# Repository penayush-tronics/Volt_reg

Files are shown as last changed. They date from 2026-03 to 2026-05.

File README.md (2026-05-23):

# Simple Voltage Regulator Board
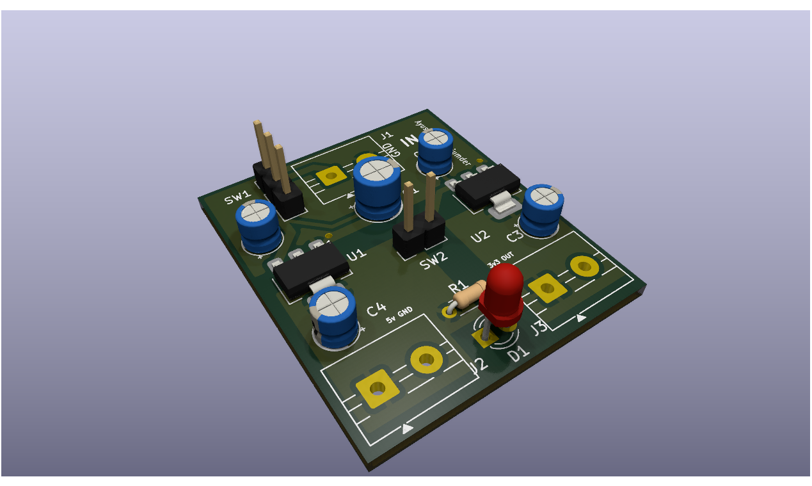
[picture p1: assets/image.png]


This is a simple voltage regulator board, which takes in between 6.5V and upto 20V input, and outputs both 5V and 3.3V, with a maximum current output of 1A. This project uses the well-known AMS1117 step-down linear voltage regulators, which are Low Dropout Regulators, meaning the voltage drop across them is less than normal linear regulators. Here there are 2 of them, 1 of which steps down (decreases) 6.5V-20V to 5V, and the other one which steps down 5V from the previous LDO, into 3.3V. 

# How to use the board: 

Here is a 3D model of the board: 

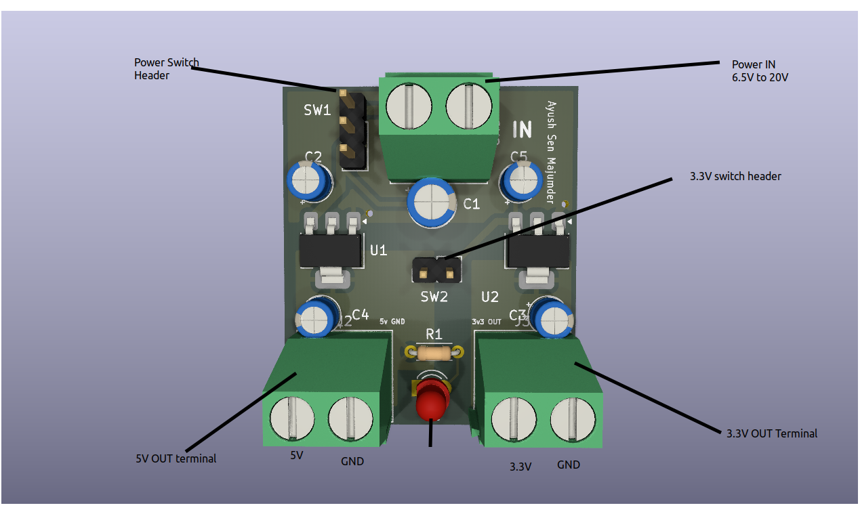
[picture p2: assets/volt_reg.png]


You will see 3 screw terminal blocks; 1 on the top side, and 2 on the bottom. The one on top, labelled IN is the input block. Here, you should screw in the input wires, which can be from a battery or any power source up to 20V. Be mindful of the polarity! You can see GND is labelled next to the ground input. 

Next, to turn the board on, add a short jumper to the 3 header pins next to the input. Short/connect the top 2 pins to connect the board to power. To disconnect, move the jumper to the bottom 2 pins. After turning it on, you will see the red LED glow. This means the 5V output and the board is turned on. You can now connect the 5V output (on the bottom left side) to anything you want to power, but once again be mindful of polarity. It is labelled on the board. 

To turn on the 3.3V output, use a short header to connect the 2 header pins in the center of the board. Now the 3.3V output is turned on (bottom right side of board) and you can connect it to anything that runs on 3.3V, such as microcontrollers and development boards. 

# Why I made this board

I found myself struggling to power my electronic components, such as motors with an arduino. You cannot run them directly with the 5V output of the arduino due to current constraints, as well as you risk frying the arduino. In such cases I struggled to power them seperately with a quality, high current power source. Normal batteries and Li-Ion rechargable batteries do not have the required voltage either, and running from USB power is not ideal. Hence I developed this regulator board, so a stable and proper 5V and 3.3V power source can be used for projects.

# Schematics 

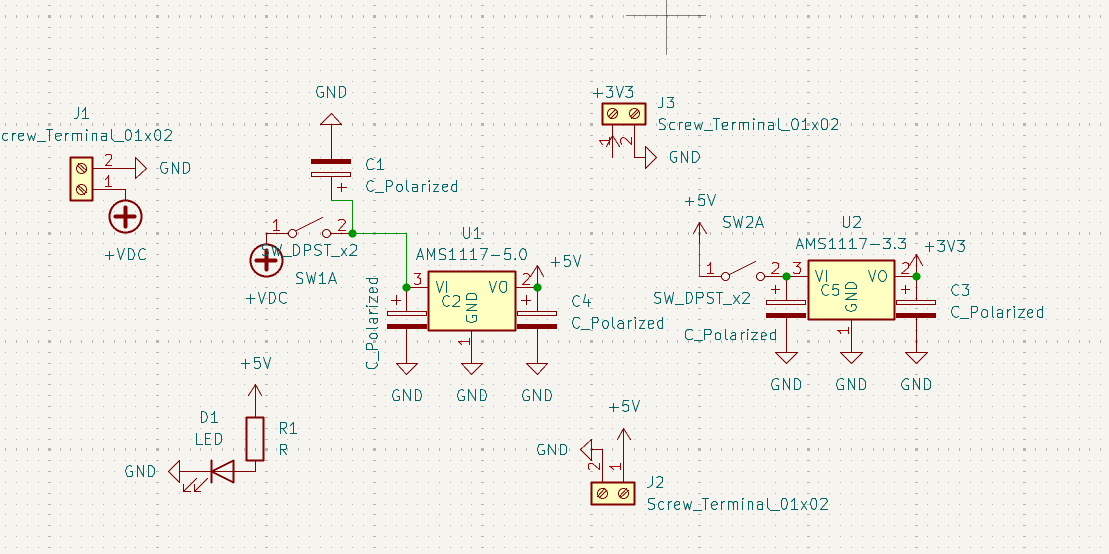
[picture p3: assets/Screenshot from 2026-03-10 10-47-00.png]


# PCB design 

KiCAD editor:
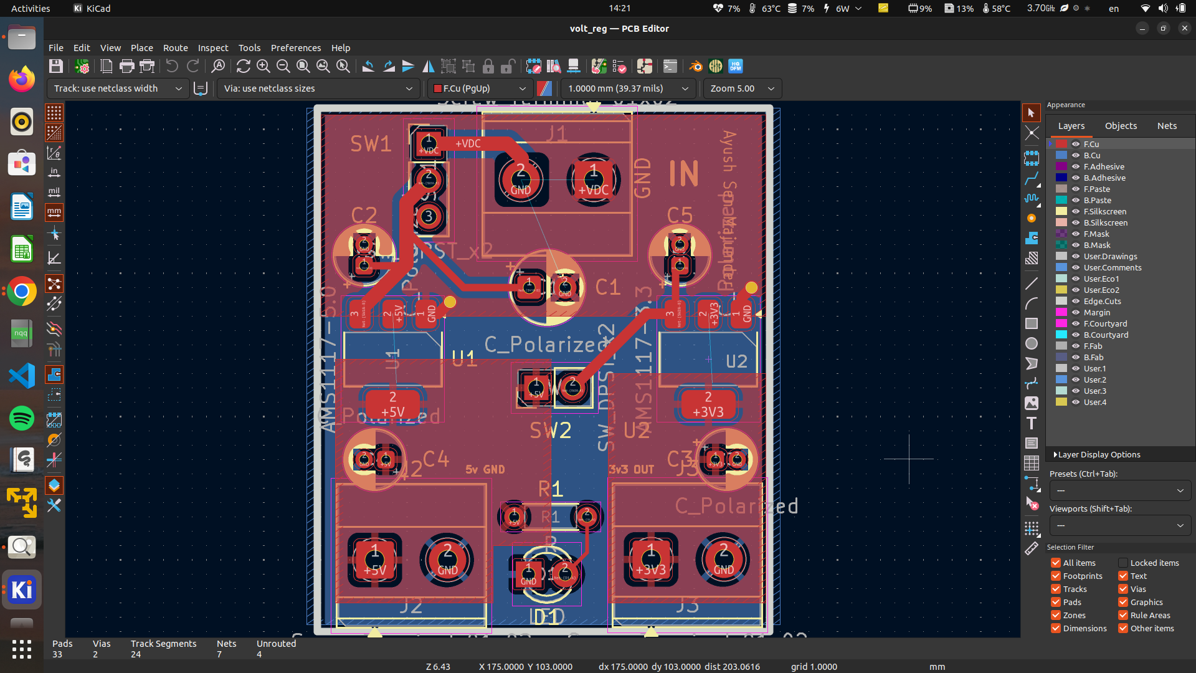
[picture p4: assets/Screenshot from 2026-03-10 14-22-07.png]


3D model-

Front side: 

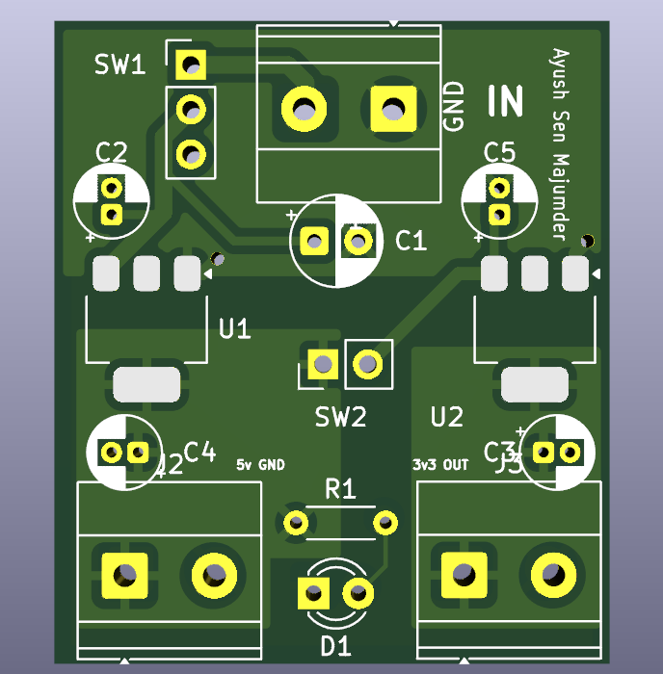
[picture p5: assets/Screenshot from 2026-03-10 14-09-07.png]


Back side:

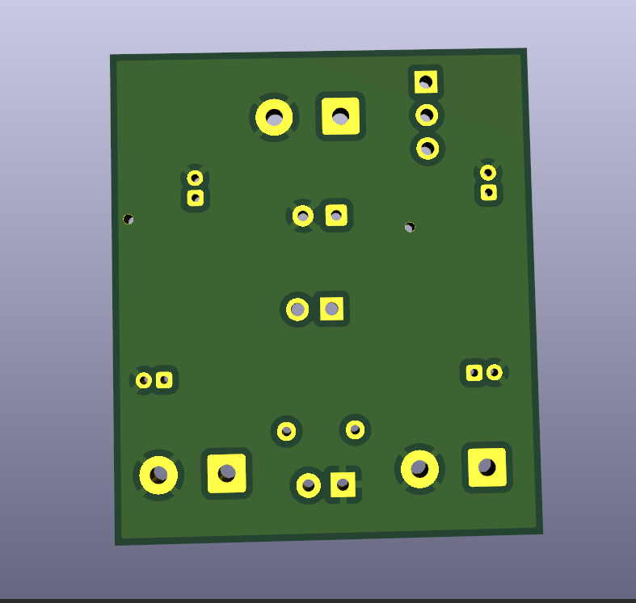
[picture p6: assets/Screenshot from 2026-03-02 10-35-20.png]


All Schematics and PCB file (including gerber zip) is available in the PCB files directory.

# It works! (Demo)

  After gathering all the parts and the PCB, I hand soldered the board together and it all works!

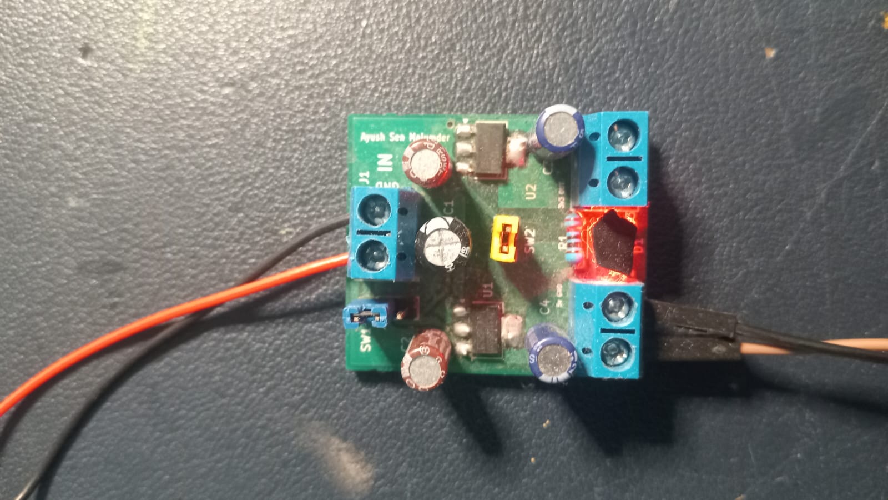
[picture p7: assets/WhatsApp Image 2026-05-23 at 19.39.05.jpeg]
  

  I have covered the red LED because it was blindingly bright!

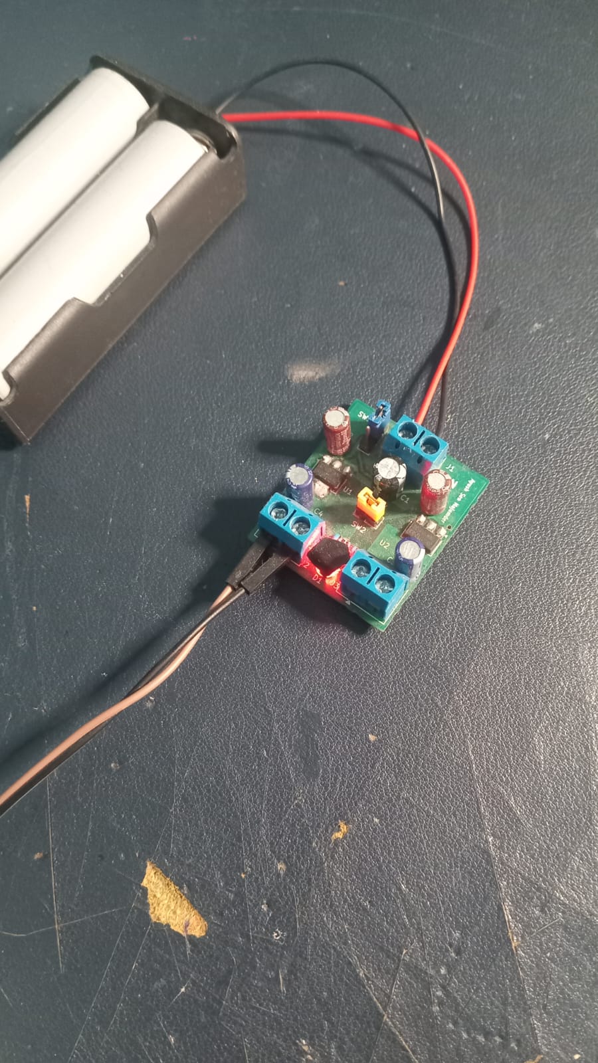
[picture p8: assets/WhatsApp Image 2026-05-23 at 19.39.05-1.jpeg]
  

  Powering it using 2 Li-Ion batteries, total voltage of ~7.5V-8V

  Here is a video showing the voltage in and out using a multimeter. 

  https://github.com/user-attachments/assets/61b3c373-3d1c-4dd0-ad89-5317c5041c4e

# Bill of materials

| Item | Qty. | Price (INR) | Ext. (INR) | Link |
| :--- | :--- | :--- | :--- | :--- |
| AMS1117-3.3V, 1A, SOT-223 Voltage Regulator IC | 2 | 9.00 | 18.00 | [Link](https://robu.in/product/ams1117-3-3v-1a-sot-223-voltage-regulator-ic-pack-of-5-ics/) |
| AMS1117-5.0V, 1A, SOT-223 Voltage Regulator IC | 2 | 6.00 | 12.00 | [Link](https://robu.in/product/ams1117-5-0v-1a-sot-223-voltage-regulator-ic-pack-of-5-ics/) |
| 100uF 25V Electrolytic Capacitor | 3 | 4.18 | 12.54 | [Link](https://robu.in/product/100uf-25v-electrolytic-capacitor-pack-of-10/) |
| 3mm Red DIP LED | 16 | 0.63 | 10.08 | [Link](https://robu.in/product/3mm-red-dip-led-pack-of-50/) |
| HY1H100M050110CD288-HYNCDZ-10uF 50V Aluminum Electrolytic | 16 | 0.65 | 10.40 | [Link](https://robu.in/product/hy1h100m050110cd288-hyncdz-10uf-50v-1-82%cf%89100khz-%c2%b120-120ma100khz-plugind5xl11mm-aluminum-electrolytic-capacitors-leaded-rohs/) |
| ERS1HM220D12OT-AISHI -22uF 50V Aluminum Electrolytic | 5 | 2.00 | 10.00 | [Link](https://robu.in/product/ers1hm220d12ot-aishi-22uf-50v-%c2%b120-plugind5xl12mm-aluminum-electrolytic-capacitors-leaded-rohs/) |
| 2 Pin 5.08mm Pitch Plug-in Screw Terminal Block | 3 | 7.00 | 21.00 | [Link](https://robu.in/product/kf301-2-pin-5-08mm-pitch-plug-in-screw-terminal-block-connector-pack-of-5/) |
| 100nf 50v Disc Capacitor | 10 | 1.00 | 10.00 | [Link](https://robu.in/product/100nf-50v-disc-capacitor/) |
| 1k Ohm 0.25W Metal Film Resistor | 35 | 0.29 | 10.15 | [Link](https://robu.in/product/1k-ohm-0-25w-metal-film-resistor-pack-of-100/) |
| PCB Fabrication | 5 | 159.8 | 943 (799 + 18% tax) | [Link](lioncircuits.com) |

Total: 1057.17 INR  (114.17 INR for components)
       
       $11.51 USD ($1.24 USD for components)

       Per board cost ~220 rs ($2.40)

Also in .csv format, in BOM.csv

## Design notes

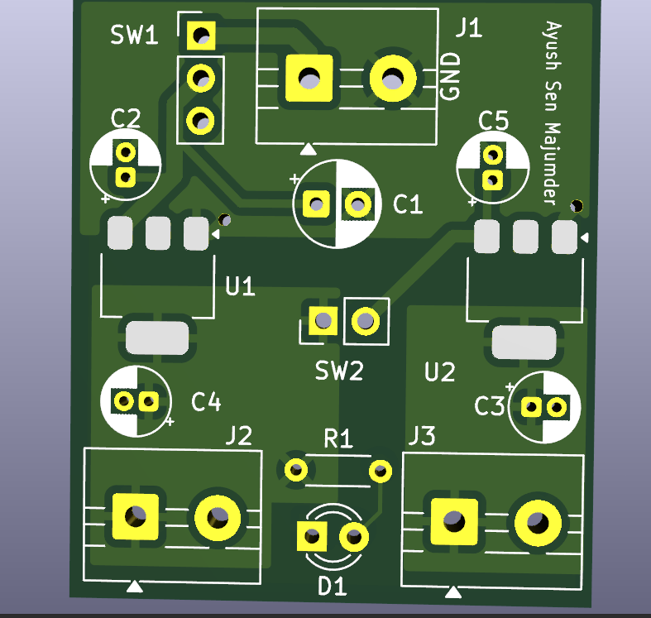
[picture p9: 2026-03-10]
assets/Screenshot from 2026-03-02 10-35-07.png

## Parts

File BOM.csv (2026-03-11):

Item | Qty. | Price (INR) | Ext. (INR) | Link
AMS1117-3.3V, 1A, SOT-223 Voltage Regulator IC | 2 | 9 | 18 | https://robu.in/product/ams1117-3-3v-1a-sot-223-voltage-regulator-ic-pack-of-5-ics/
AMS1117-5.0V, 1A, SOT-223 Voltage Regulator IC | 2 | 6 | 12 | https://robu.in/product/ams1117-5-0v-1a-sot-223-voltage-regulator-ic-pack-of-5-ics/
100uF 25V Electrolytic Capacitor | 3 | 4.18 | 12.54 | https://robu.in/product/100uf-25v-electrolytic-capacitor-pack-of-10/
3mm Red DIP LED | 16 | 0.63 | 10.08 | https://robu.in/product/3mm-red-dip-led-pack-of-50/
HY1H100M050110CD288-HYNCDZ-10uF 50V Aluminum Electrolytic | 16 | 0.65 | 10.4 | https://robu.in/product/hy1h100m050110cd288-hyncdz-10uf-50v-1-82%cf%89100khz-%c2%b120-120ma100khz-plugind5xl11mm-aluminum-electrolytic-capacitors-leaded-rohs/
ERS1HM220D12OT-AISHI -22uF 50V Aluminum Electrolytic | 5 | 2 | 10 | https://robu.in/product/ers1hm220d12ot-aishi-22uf-50v-%c2%b120-plugind5xl12mm-aluminum-electrolytic-capacitors-leaded-rohs/
2 Pin 5.08mm Pitch Plug-in Screw Terminal Block | 3 | 7 | 21 | https://robu.in/product/kf301-2-pin-5-08mm-pitch-plug-in-screw-terminal-block-connector-pack-of-5/
100nf 50v Disc Capacitor | 10 | 1 | 10 | https://robu.in/product/100nf-50v-disc-capacitor/
1k Ohm 0.25W Metal Film Resistor | 35 | 0.29 | 10.15 | https://robu.in/product/1k-ohm-0-25w-metal-film-resistor-pack-of-100/
PCB Fabrication | 5 | 188.6 | 943 | lioncircuits.com

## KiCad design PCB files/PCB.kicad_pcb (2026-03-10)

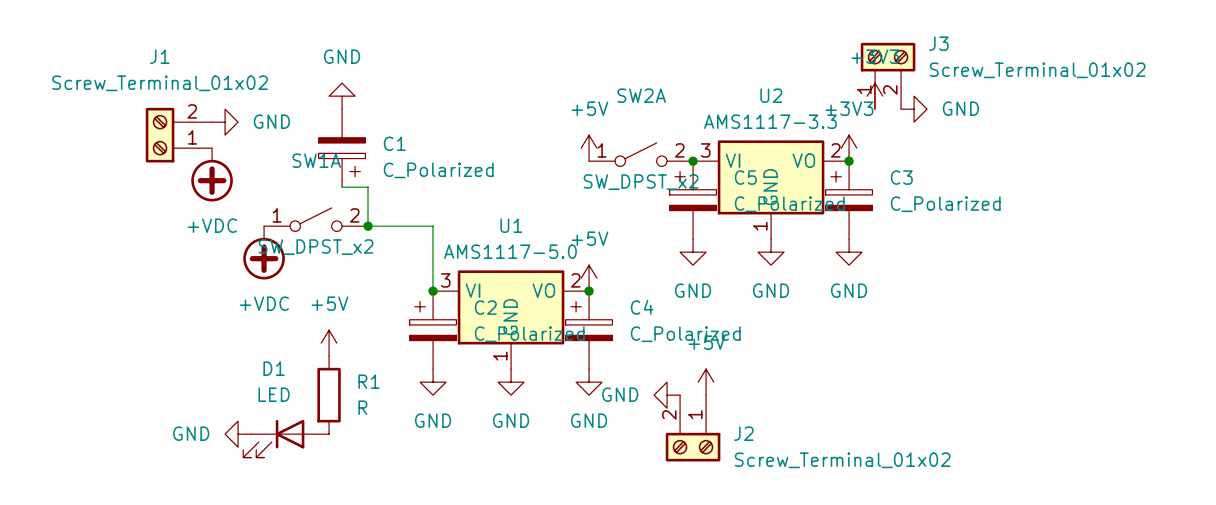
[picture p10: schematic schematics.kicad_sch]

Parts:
C1: C_Polarized; CP_Radial_D5.0mm_P2.50mm
C2, C3, C4, C5: C_Polarized; CP_Radial_D4.0mm_P1.50mm
D1: LED; LED_D3.0mm
J1, J2, J3: Screw_Terminal_01x02; TerminalBlock_MaiXu_MX126-5.0-02P_1x02_P5.00mm
R1: R; R_Axial_DIN0204_L3.6mm_D1.6mm_P5.08mm_Horizontal
SW1: SW_DPST_x2; PinHeader_1x03_P2.54mm_Vertical
SW2: SW_DPST_x2; PinHeader_1x02_P2.54mm_Vertical
U1: AMS1117-5.0; SOT-223-3_TabPin2
U2: AMS1117-3.3; SOT-223-3_TabPin2

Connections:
+3V3: C3.1, J3.1, U2.2 (VO)
+5V: C4.1, J2.1, R1.1, SW2.1 (A), U1.2 (VO)
+VDC: J1.1, SW1.1 (A)
GND: C1.2, C2.2, C3.2, C4.2, C5.2, D1.1 (K), J1.2, J2.2, J3.2, U1.1 (GND), U2.1 (GND)
unnamed: D1.2 (A), R1.2
unnamed: C1.1, C2.1, SW1.2 (B), U1.3 (VI)
unnamed: C5.1, SW2.2 (B), U2.3 (VI)

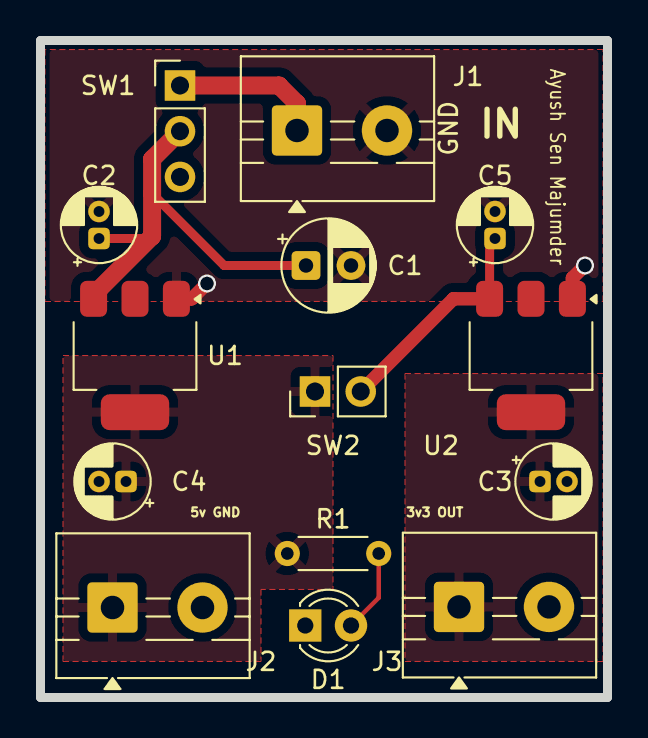
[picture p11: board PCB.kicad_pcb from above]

Board: 2 copper layers, 31.5 x 36.5 mm, 14 parts (0 on the bottom side), 7 nets.

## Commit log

2026-03-10 Updated the repo for complete project
    [BOM.csv, PCB.kicad_pcb, schematics.kicad_sch]
2026-03-10 Updated BOM
    [BOM.csv]
2026-03-10 Added PCB KiCAD
2026-03-11 updated BOM in readme and .csv
    [BOM.csv]
2026-03-13 fixed per board cost
